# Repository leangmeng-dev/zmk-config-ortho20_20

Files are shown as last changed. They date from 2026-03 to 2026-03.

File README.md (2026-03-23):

# 20/20 Split Keyboard

A wireless, hotswap, ortholinear split keyboard powered by [ZMK firmware](https://zmk.dev/).

<p align="center">
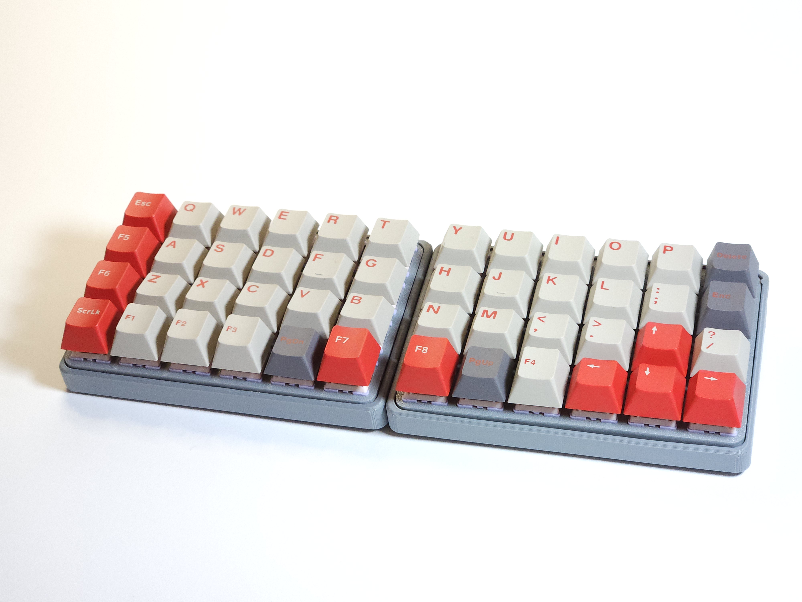
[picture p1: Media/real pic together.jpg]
20/20 Split — Together
  
</p>

<p align="center">
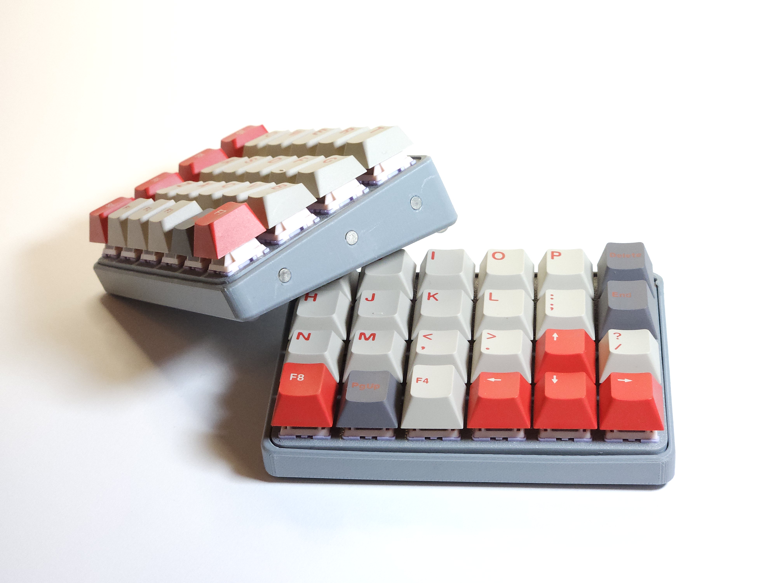
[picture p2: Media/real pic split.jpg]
20/20 Split — Split Mode
  
</p>

---

## Features

| | |
|---|---|
| **Layout** | Plank-ish 40 % when magnetically attached · Ortholinear 24 + 24 when split |
| **Hotswap** | Cherry MX compatible hotswap sockets — swap switches without soldering |
| **Wireless** | Bluetooth Low Energy via dual Nice!Nano v2 Clones (nRF52840)  |
| **Customizable** | Remap keys live with [ZMK Studio](https://zmk.studio/) — no reflashing required |
| **Battery** | 801350 3.7 V Li-Po per half with on/off slide switch |
| **3D Printed** | Fully printable case with magnet attachment system |

---

## Links

| Resource | URL |
|---|---|
| **Build Video** | [YouTube](https://www.youtube.com/watch?v=XWv2SwuP9wc) |
| **PDF Manual** | [20_20 split keyboard BOM and instructions.pdf](Media/20_20%20split%20keyboard%20BOM%20and%20instructions.pdf) |
| **ZMK Studio** | [zmk.studio](https://zmk.studio/) |
| **3D Printable Files** | [MakerWorld](https://makerworld.com/en/models/2563301/)|
| **ZMK Docs** | [zmk.dev](https://zmk.dev/) |

---

## Tools Used

| Tool | Purpose |
|---|---|
| [Keyboard Layout Editor](https://www.keyboard-layout-editor.com/#/) | Layout creation |
| [Swillkb Plate Builder](http://builder.swillkb.com/) | Plate DXF generation |
| [ZMK Shield Wizard](https://shield-wizard.genteure.workers.dev/) | ZMK shield configuration |
| [Keymap Drawer](https://keymap-drawer.streamlit.app/) | Keymap visualization |

---

## Default Keymap

<p align="center">
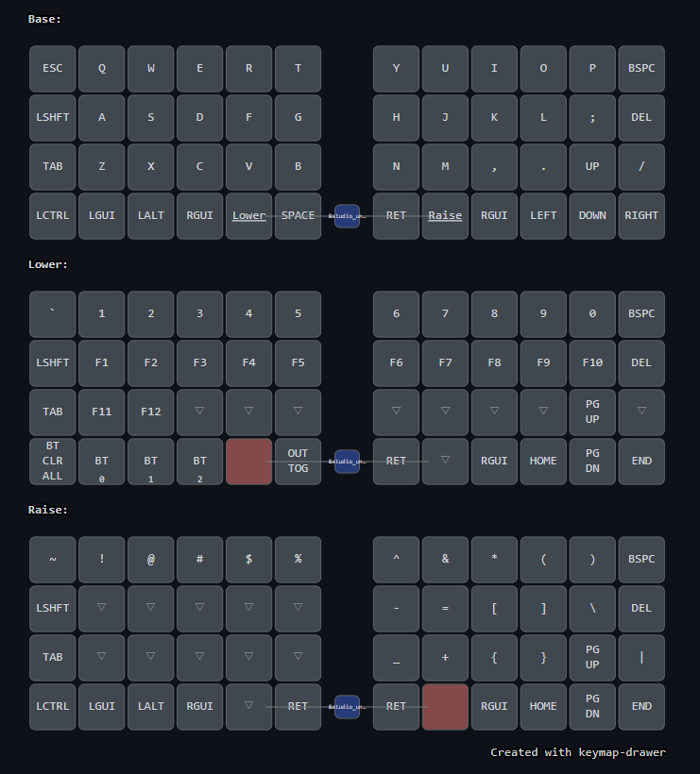
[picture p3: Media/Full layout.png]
Full keyboard layout
  
</p>

User keymap is located at [`config/ortho20_20.keymap`](config/ortho20_20.keymap). You can also remap keys live via [ZMK Studio](https://zmk.studio/) — no reflashing needed.

---

## Combos

### ZMK Studio Unlock

Hold two bottom-row keys simultaneously to unlock ZMK Studio:

<p align="center">
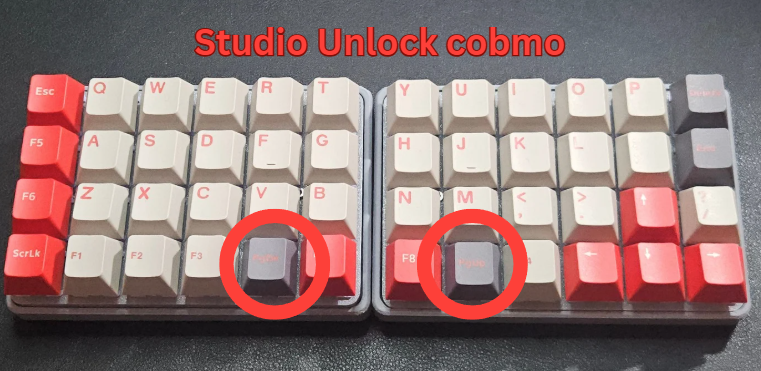
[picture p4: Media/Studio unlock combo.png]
ZMK Studio unlock combo
  
</p>

### Bluetooth Profile Combos

<p align="center">
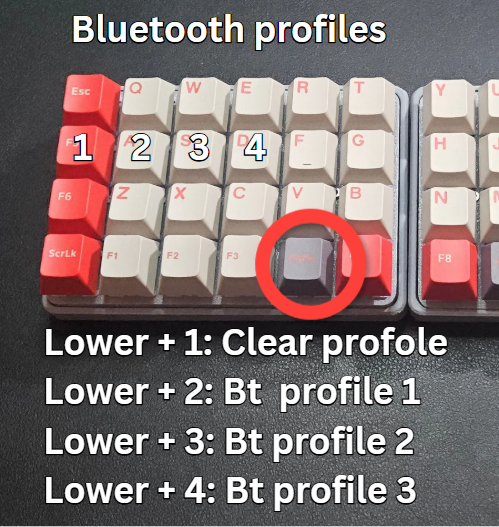
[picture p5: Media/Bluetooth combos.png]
Bluetooth combos
  
</p>

---

## Bill of Materials

> [!NOTE]
> **Additionally required (not listed below):** soldering iron, solder, [hookup wires](https://www.aliexpress.com/item/1005005048098404.html), [rubber feet](https://www.aliexpress.com/item/1005002705337380.html), heatshrink tubing, hot glue, and superglue.

| # | Item | Qty | Link |
|:-:|---|:---:|:----:|
| 1 | **Cherry MX Switches** | 48 | [AliExpress](https://www.aliexpress.com/item/1005007345651159.html) |
| 2 | **Pro Micro nRF52840** (Nice!Nano v2 clone) | 2 | [AliExpress](https://www.aliexpress.com/item/1005006995289476.html) |
| 3 | **MX Hotswap Sockets** | 48 | [AliExpress](https://www.aliexpress.com/item/1005004290562374.html) |
| 4 | **1N4148 Diodes** | 48 | [AliExpress](https://www.aliexpress.com/item/1005006245109375.html) |
| 5 | **M2 × 10 mm SHCS Screws** | 4 | [Bambu Lab](https://eu.store.bambulab.com/products/m2-socket-head-cap-machine-screws-shcs?id=48672759054684) |
| 6 | **M2 × 4 mm SHCS Screws** | 4 | [Bambu Lab](https://eu.store.bambulab.com/products/m2-socket-head-cap-machine-screws-shcs?id=48672758923612) |
| 7 | **M2 × 6 mm Standoffs** | 4 | [AliExpress](https://www.aliexpress.com/item/1005006049595637.html) |
| 8 | **4 × 2 mm Round Magnets** | 6 | [Bambu Lab](https://eu.store.bambulab.com/products/round-magnet?id=47966966579548) |
| 9 | **Kapton Tape** | 1 | [AliExpress](https://www.aliexpress.com/item/1005007518587827.html) |
| 10 | **Copper Wire** | 1 | [AliExpress](https://www.aliexpress.com/item/1005009078359338.html) |
| 11 | **801350 3.7 V Li-Po Battery** | 2 | [AliExpress](https://www.aliexpress.com/item/1005007117105334.html) |
| 12 | **Slide Switch** (on/off) | 2 | [AliExpress](https://www.aliexpress.com/item/33013437240.html) |
| 13 | **EVA Foam** *(optional, recommended)* | — | [AliExpress](https://www.aliexpress.com/item/1005002621956105.html) |
| 14 | **JST Battery Connectors** *(optional, recommended)* | — | [AliExpress](https://www.aliexpress.com/item/1005003390942788.html) |

---

## Build Instructions

> [!TIP]
> Watch the full **[Build Video on YouTube](https://www.youtube.com/watch?v=XWv2SwuP9wc)** for a detailed wiring walkthrough.

1. **Prepare everything** — Print the case parts and gather all BOM materials.
2. **Insert hotswap sockets** into the hotswap plate.
3. **Assemble plates** — Attach the hotswap plate to the switch plate using **M2 × 10 mm screws** and **6 mm standoffs**.
4. **Insert the switches** into the assembled plate.
5. **Solder diodes** — Solder the 1N4148 diodes to the hotswap sockets, placing them in their slots in the hotswap plate.
6. **Wire the rows** — Connect the other legs of the diodes together to form rows.
7. **Insulate rows** — Cover row wiring with **kapton tape** to prevent shorts.
8. **Wire the columns** — Cut copper wire to length and solder to the second hotswap contact to form columns.
9. **Connect to controller** — Wire rows and columns to the Nice!Nano v2 (see [Pinout](#-pinout) below).
10. **Solder power circuit** — Wire the slide switch, battery, and controller together.
11. **Flash firmware** — Flash the firmware and test all keys.

    > ⚠️ The **right half will not work** unless the left half is powered on.

12. **Final assembly** — Seat the controller in the case, secure with hot glue, insert switches into sockets, and screw on the bottom plate with **M2 × 4 mm screws**.
13. **Finishing touches** — Add keycaps and glue the magnets into the case.
14. **Repeat** for the second half — enjoy your new keyboard! 🎉

---

## Pinout

<p align="center">
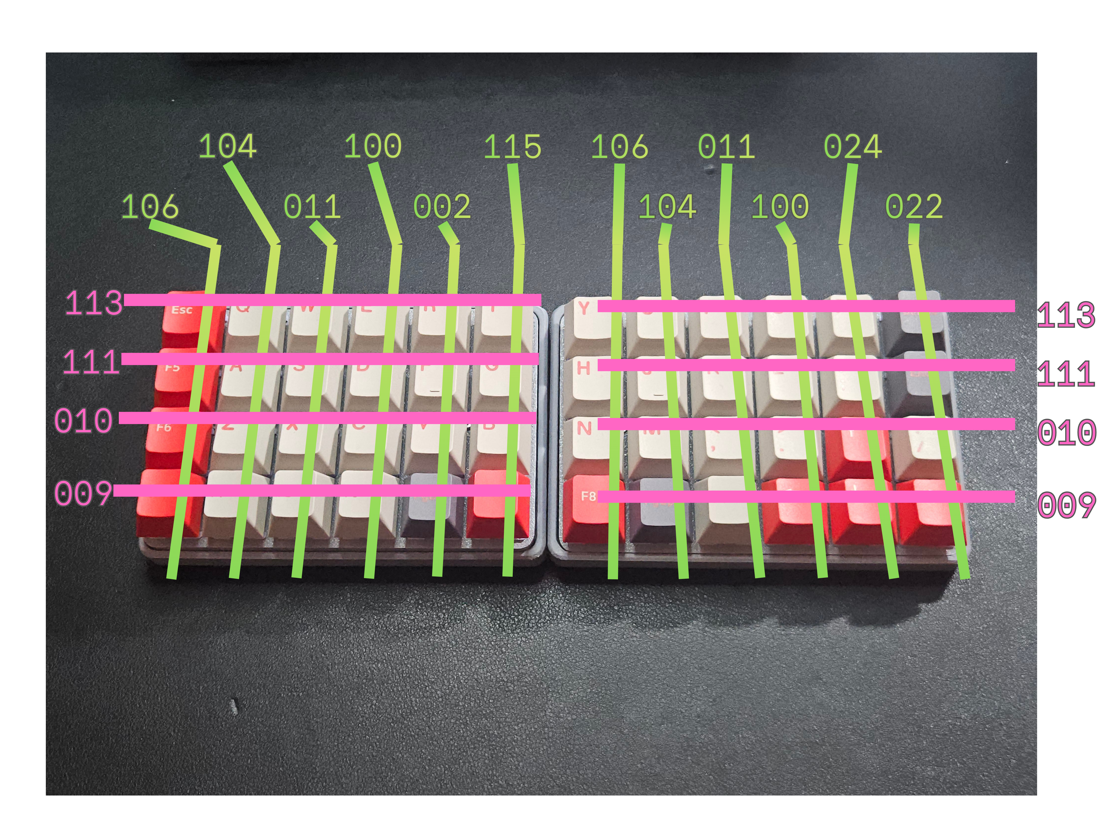
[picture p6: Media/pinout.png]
Wiring pinout diagram
  
</p>

> [!NOTE]
> Columns 0–3 and all rows share the same pins on both halves. Columns 4–5 differ between left (`002`, `115`) and right (`024`, `022`).

---

## Firmware

Firmware is built automatically via GitHub Actions. To install:

1. Go to the **[Actions](../../actions)** tab on this repo.
2. Click the latest successful workflow run.
3. Download the firmware `.uf2` files from the **Artifacts** section.
4. Put each Nice!Nano v2 into bootloader mode (double-tap reset) and copy the corresponding `.uf2` file.

For more details see the [ZMK firmware installation guide](https://zmk.dev/docs/user-setup#installing-the-firmware).

### Build Artifacts

| Artifact | Description |
|---|---|
| `ortho20_20_left_with_studio` | Left half — includes ZMK Studio support |
| `ortho20_20_right` | Right half (peripheral) |
| `settings_reset` | Flash to either half to factory-reset stored settings |

### Premade Firmware

For convenience, you can download the premade firmware here:
- [firmware .zip](Premade%20Firmware/firmware%20.zip)

### ZMK Studio

This firmware ships with **ZMK Studio** enabled on the left half. Connect via USB, open [zmk.studio](https://zmk.studio/), and remap your keys on the fly.

---

<p align="center">
  <em>Designed & built by <a href="https://github.com/vostoklabs">Vostok Labs</a></em>
</p>

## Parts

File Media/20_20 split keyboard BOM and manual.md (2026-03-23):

# 20 20 split keyboard

**Features:**

**Hotswap**  
**Wireless:** Bluetooth support via ZMK.  
**Customizable:**  via ZMK Studio, at [zmk.studio](https://zmk.studio/)

**Layout**: Plank-ish 40% when magnetically attached, ortholinear 24 + 24 when split

**Build Video:** [YouTube](https://www.youtube.com/watch?v=XWv2SwuP9wc)  
**Firmware and more details**: [GitHub](https://github.com/vostoklabs/zmk-config-ortho20_20)

# 

# 

Pinout

Left Half                                              Right Half

|Columns:  0 - 106 1 - 104 2 - 011 3 - 100 4 - 002 5 - 115|Rows: 0 - 113 1 - 111 2 - 010 3 - 009||Columns: 0 - 106 1 - 104 2 - 011 3 - 100 4 - 024 5 - 022|Rows: 0 - 113 1 - 111 2 - 010 3 - 009|
|-|-|-|-|-|

# 

# Bill of materials

Assuming you have solder, solder iron, and some [wires](https://www.aliexpress.com/item/1005005048098404.html?spm=a2g0o.order_list.order_list_main.73.47741802kB9uqg)  
Additionally you will need some [rubber feet](https://www.aliexpress.com/item/1005002705337380.html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), heatshrinks, hot glue and superglue

|Item|Link|Amount|
|-|-|-|
|Mechanical Cherry switches|[Link](https://www.aliexpress.com/item/1005007345651159.html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)|48|
|Pro micro NRF52840 controller ( Nice!Nano v2 clone)|[Link](https://www.aliexpress.com/item/1005006995289476.html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)|2|
|Hot Swap Sockets  For Mx Cherry|[Link](https://www.aliexpress.com/item/1005004290562374.html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)|48|
|Diodes 1N4148|[Link](https://www.aliexpress.com/item/1005006245109375.html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)|48|
|M2, 10 mm Socket Head Cap Machine Screws (SHCS)|[Link](https://eu.store.bambulab.com/products/m2-socket-head-cap-machine-screws-shcs?id=48672759054684)|4|
|M2, 4 mm Socket Head Cap Machine Screws (SHCS)|[Link](https://eu.store.bambulab.com/products/m2-socket-head-cap-machine-screws-shcs?id=48672758923612)|4|
|M2, 6mm stand offs|[Link](https://www.aliexpress.com/item/1005006049595637.html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)|4|
|4 by 2 mm magnets|[Link](https://eu.store.bambulab.com/products/round-magnet?id=47966966579548)|6|
|Kapton tape|[Link](https://www.aliexpress.com/item/1005007518587827.html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)|1|
|Copper wire|[Link](https://www.aliexpress.com/item/1005009078359338.html?spm=a2g0o.order_list.order_list_main.56.47741802kB9uqg)|1|
|801350 3.7V Li-Po Battery|[Link](https://www.aliexpress.com/item/1005007117105334.html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)|2|
|Slide switch|[Link](https://www.aliexpress.com/item/33013437240.html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)|2|
|EVA foam (optional but recommended)|[Link](https://www.aliexpress.com/item/1005002621956105.html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)||
|JST battery connectors (optional but recommended)|[Link](https://www.aliexpress.com/item/1005003390942788.html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)||

## 

## Build instructions

**For Wiring process reference Build Video:** [YouTube](https://www.youtube.com/watch?v=XWv2SwuP9wc)

### **Step 1:**  Prepare everything (Printed part and materials)

### **Step 2:** Put Hotswap sockets in the hotswap plate

### **Step 3**: Put together hotswap plate and switch plate, screw them using m2x10 screws and standoffs

### **Step 4:** Insert the switches

### **Step 5**: Insert and solder the diodes to the hotswap sockets, placing diodes in their place in the hotswap plate

### **Step 6:** Wire other legs of the diodes to create rows

### **Step 7:** Isolate the rows using kapton tape

### **Step 8:** Cut the copper wire for the columns and wire it to other hotswap contact

### **Step 9:** Wire rows and columns to the controller

### **Step 10:** Solder on/off switch with battery and the controller

### **Step 11:** Flash the firmware to the board and test it (Remember that right half wont work if the left is not running)

### **Step 12:** Insert controller into the case, add some hot glue to hold it into the place, insert switch in its socket and screw the bottom of the case to the plate using m2x4 screws

### **Step 13:** Add keycaps and glue the magnets to the case

### **Step 14:** Repeat the same for the other half and enjoy your new keyboard

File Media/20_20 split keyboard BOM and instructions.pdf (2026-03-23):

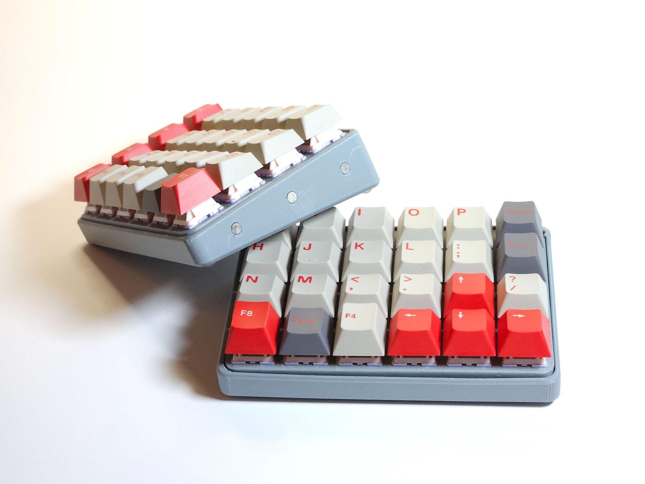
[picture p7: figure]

# 20 20 split keyboard

Features:

Hotswap
Wireless: Bluetooth support via ZMK. Customizable: via ZMK Studio, at zmk.studio

Layout: Plank-ish 40% when magnetically attached, ortholinear 24 + 24 when split

Build Video: YouTube (https://www.youtube.com/watch?v=XWv2SwuP9wc)
Firmware and more details: GitHub (https://github.com/vostoklabs/zmk-config-ortho20_20)

## Pinout

Left Half | Right Half
Columns:

0 - 106
1 - 104
2 - 011
3 - 100
4 - 002
5 - 115

Rows:

0 - 113
1 - 111
2 - 010
3 - 009

Columns:

0 - 106
1 - 104
2 - 011
3 - 100
4 - 024
5 - 022

Rows:

0 - 113
1 - 111
2 - 010
3 - 009

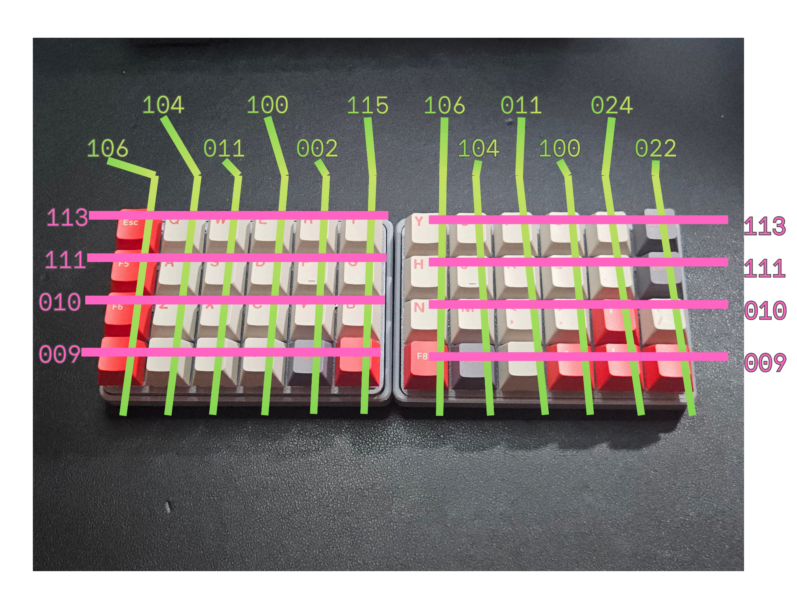
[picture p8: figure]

If you want to use prebuild firmware, you have to use provided pinout for the matrix

# Bill of materials

Assuming you have solder, solder iron, and some wires (https://www.aliexpress.com/item/1005005048098404.html) Additionally you will need some rubber feet, (https://www.aliexpress.com/item/1005002705337380.html?curPageLogUid=h4db4KzhGvYu) heatshrinks, hot glue

### and superglue

Item | Link | Amount
Mechanical Cherry switches | Link (https://www.aliexpress.com/item/1005007345651159.html?curPageLogUid=zCC6svikv5Hc) | 48
Pro micro NRF52840 controller ( Nice!Nano v2 clone) | Link (https://www.aliexpress.com/item/1005006995289476.html?curPageLogUid=VJ4Cad4XkmFS) | 2
Hot Swap Sockets For Mx Cherry | Link (https://www.aliexpress.com/item/1005004290562374.html?curPageLogUid=oQQIaalNlcGV) | 48
Diodes 1N4148 | Link (https://www.aliexpress.com/item/1005006245109375.html?curPageLogUid=OhJwy5f5LVsx) | 48
M2, 10 mm Socket Head Cap Machine Screws (SHCS) | Link (https://eu.store.bambulab.com/products/m2-socket-head-cap-machine-screws-shcs?id=48672759054684) | 4
M2, 4 mm Socket Head Cap Machine Screws (SHCS) | Link (https://eu.store.bambulab.com/products/m2-socket-head-cap-machine-screws-shcs?id=48672758923612) | 4
M2, 6mm stand offs | Link (https://www.aliexpress.com/item/1005006049595637.html) | 4
4 by 2 mm magnets | Link (https://eu.store.bambulab.com/products/round-magnet?id=47966966579548) | 6
Kapton tape | Link (https://www.aliexpress.com/item/1005007518587827.html?curPageLogUid=FLnTGx29WStB) | 1
Copper wire | Link (https://www.aliexpress.com/item/1005009078359338.html) | 1
801350 3.7V Li-Po Battery | Link (https://www.aliexpress.com/item/1005007117105334.html?curPageLogUid=DpbnRSMFXGC4) | 2
Slide switch | Link (https://www.aliexpress.com/item/33013437240.html?curPageLogUid=KtTWqbb8iwSd) | 2
EVA foam (optional but recommended) | Link (https://www.aliexpress.com/item/1005002621956105.html?curPageLogUid=reGzNZ3dRqrA)
JST battery connectors (optional but recommended) | Link (https://www.aliexpress.com/item/1005003390942788.html?curPageLogUid=SfgaTyrJlQpx)

## Build instructions

For Wiring process reference Build Video: YouTube (https://www.youtube.com/watch?v=XWv2SwuP9wc)

Step 1: Prepare everything (Printed part and materials)
Step 2: Put Hotswap sockets in the hotswap plate
Step 3: Put together hotswap plate and switch plate, screw them using m2x10 screws and standoffs
Step 4: Insert the switches
Step 5: Insert and solder the diodes to the hotswap sockets, placing diodes in their place in the hotswap plate
Step 6: Wire other legs of the diodes to create rows
Step 7: Isolate the rows using kapton tape
Step 8: Cut the copper wire for the columns and wire it to other hotswap contact
Step 9: Wire rows and columns to the controller
Step 10: Solder on/off switch with battery and the controller
Step 11: Flash the firmware to the board and test it (Remember that right half wont work if the left is not running)
Step 12: Insert controller into the case, add some hot glue to hold it into the place, insert switch in its socket and screw the bottom of the case to the plate using m2x4 screws
Step 13: Add keycaps and glue the magnets to the case
Step 14: Repeat the same for the other half and enjoy your new keyboard

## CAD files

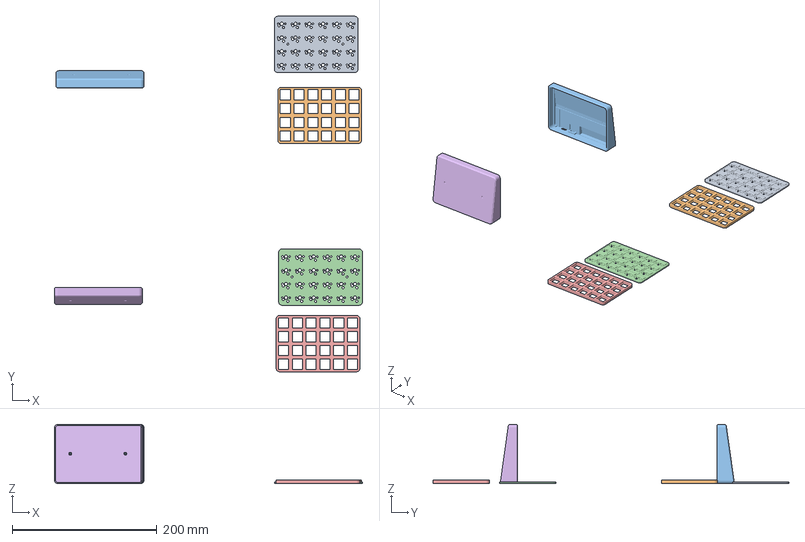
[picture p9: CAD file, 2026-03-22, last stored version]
3D files/retro split 40 plate and hotwsap.3mf
425.6 x 491.3 x 82.2 mm
Hotswap and wiring plate x 2
top plate x 2
case
right side fixed hole aligmnet.step

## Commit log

2026-03-22 added 3mf for the case
    [retro split 40 plate and hotwsap.3mf]
2026-03-23 Readme remap
    [retro split 40 plate and hotwsap.3mf]
2026-05-17 fixing board
